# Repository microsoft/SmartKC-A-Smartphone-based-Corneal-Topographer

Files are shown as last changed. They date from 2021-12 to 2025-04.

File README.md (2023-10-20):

# SmartKC: Analysis Pipeline

This directory contains the code for the image processing pipeline for *SmartKC*. The input to the system is a *mire* image and the output are the corneal topography heatmaps (*axial* and *tangential*), along with the quantitative metrics: *sim-k, diff, mean-k, aCLMI, PPK, KISA*.

The aim of this README is to describe in detail the setup and image processing pipeline for ease of understanding and usage by a beginner user. The readme describes in detail the analysis pipeline, example code snippets, details on the functions and parameters.

The figure below illustrates the (a) SmartKC system setup, (b) LED light arrangement, (c) 3D-printed conical placido clip-on attachment, (d) image capture of a subject’s eye, and (e) captured image of the cornea with
placido disc reflection (called mires).

<p align='center'>
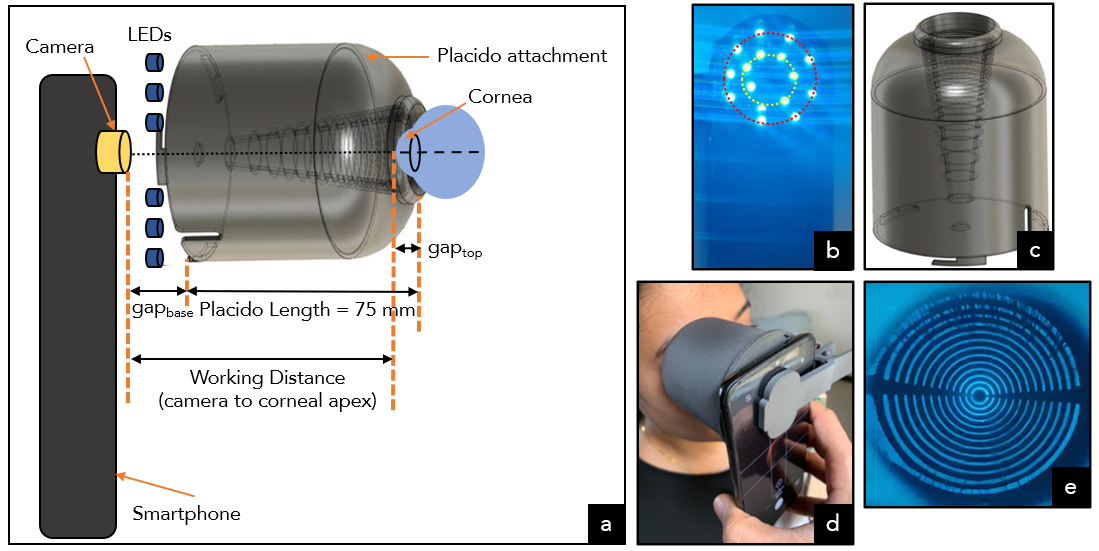
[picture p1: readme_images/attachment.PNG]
      
</p>

## Dependencies

```
* Python3.8.XX
* numpy==1.18.1
* opencv-contrib-python==4.4.0.46
* scikit-image==0.18.1
* scikit-learn
* scipy
* zernike==0.0.15
* pandas==1.1.1
* matplotlib==3.2.2
* Flask==1.1.2
* seaborn==0.11.0
* tqdm==4.56.0
* Pytorch (torch, torchvision and other dependencies for Pytorch)
```

These are all easily installable via, e.g., `pip install numpy`. Any reasonably recent version of these packages should work. It is recommended to use a python `virtual` environment to setup the dependencies and the code.

### External Libraries

* [Zernike](https://github.com/jacopoantonello/zernike)
* [Fingerprint-Enhancement-Python](https://github.com/Utkarsh-Deshmukh/Fingerprint-Enhancement-Python)

**Note**: The zernike polynomial smoothening function has been modified from the version above. Please use the module at location: `/SmartKC/data/zernike` (I yet am to make a pull request to the original repository).

## Image Processing Pipeline Overview

<p align='center'>
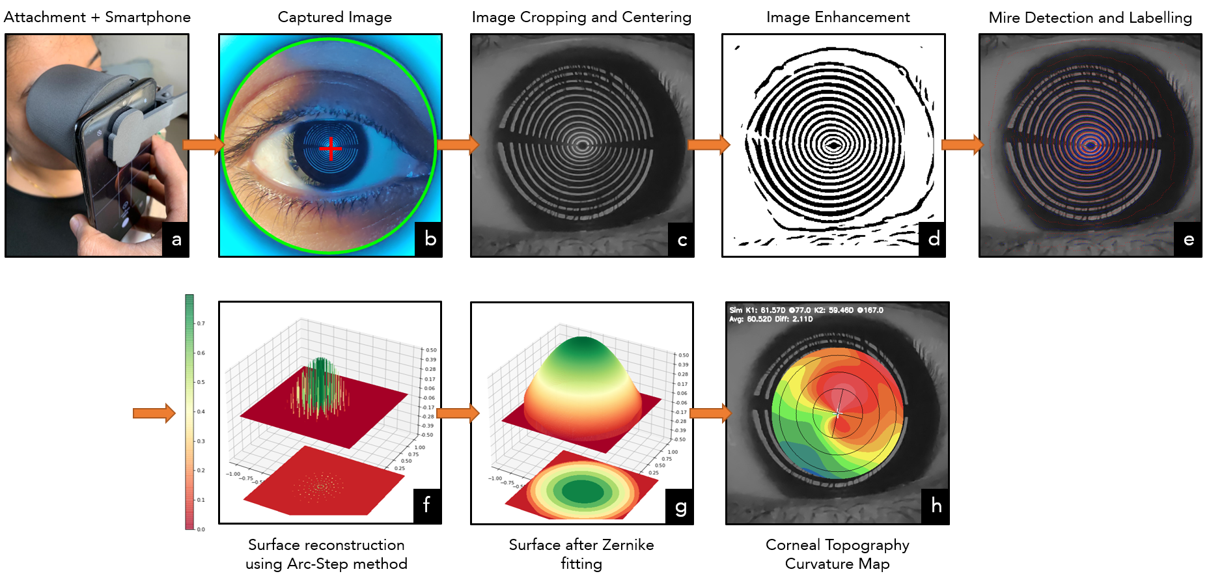
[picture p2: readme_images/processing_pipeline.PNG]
      
</p>

The image analysis pipeline takes as input the image collected via our setup (3D attachment and smartphone), and outputs the corneal topography heatmaps along with quantitative values. The analysis pipeline first performs **pre-processing** (*image cropping, mire segmentation, and center detection*) on the input image. The next step is to get the **mire-placido mapping**, this is followed by estimation of **placido ring location and working distance**. The final corneal topography is estimated by running the **Arc-Step method** followed by zernike polynomial based smoothening.

## Example Code Snippet:

```python
from main import *

# assuming args has camera-parameters, base_dir, start/end angle, jump, model-file, working_distance, number of mires, upsample flag

# getting parameters for corneal_top_obj
f_inv_20_5 = np.poly1d([3583.52156815, -17.31674123]) # 5 mm gap2, mire_21, id_20
sensor_dims = (
    float(args.camera_params.split()[0]),
    float(args.camera_params.split()[1]),
)  # "4.27, 5.68, 4.25"
f_len = float(args.camera_params.split()[2]) # focal length of the camera

# create the corneal_top_gen class object
corneal_top_obj = corneal_top_gen(
    args.model_file, args.working_distance, sensor_dims, 
    f_len, args.start_angle, args.end_angle, args.jump, 
    args.upsample, args.n_mires, f_inv_20_5,
    )

# get details for current test image
base_dir = args.base_dir  # base directory
skip_angles = [[-1, -1], [-1, -1]]
center = (-1, -1)
image_name = "./data/test_image.jpg"

# call function to run pipeline and generate_topography_maps
# expects image to be in .jpg format
error = corneal_top_obj.generate_topography_maps(
    base_dir,
    image_name,
    center=center,
    downsample=True,
    blur=True,
    err1=[args.gap1],
    err2=[args.gap2],
    )
```

**Note**: To understand the different parameters, please go through the detailed documentation for each function and the input parameters below.

## Running Script

`python main.py --n_mires 22 --working_distance 75.0 --camera_params "4.8 6.4 4.755" --model_file ./data/ring_distribution.txt --base_dir data/sample_images/ --center_selection auto --mire_seg_method dl --mire_loc_method graph_cluster --verbose`

Please place your csv files containing meta data generated by the smart kc app in the `base_dir` if you want the pipeline to automatically pick up the center values as marked in the smartkc app

There are 2 arguments which control how the segmentation and mire localization is done. 

(1) `--mire_seg_method` determines how the mires are segmented. Currently, we support 2 methods for segmentation, `image_proc` which does segmentation via traditional image processing, and `dl` which does image segmentation using a U-Net based segmentor model.

(2) `--mire_loc_method` determines how mires are localized. Currently, we support 2 methods - `radial_scan` which determines mire locations via the radial-scanning algorithm mentioned in the paper, and `graph_cluster` which applies graph-based connected-component search to locate mires by utilizing spatial information. More details coming.

We also support a `--verbose` flag to turn on logging, if required.

## Sample outputs

<p align='center'>
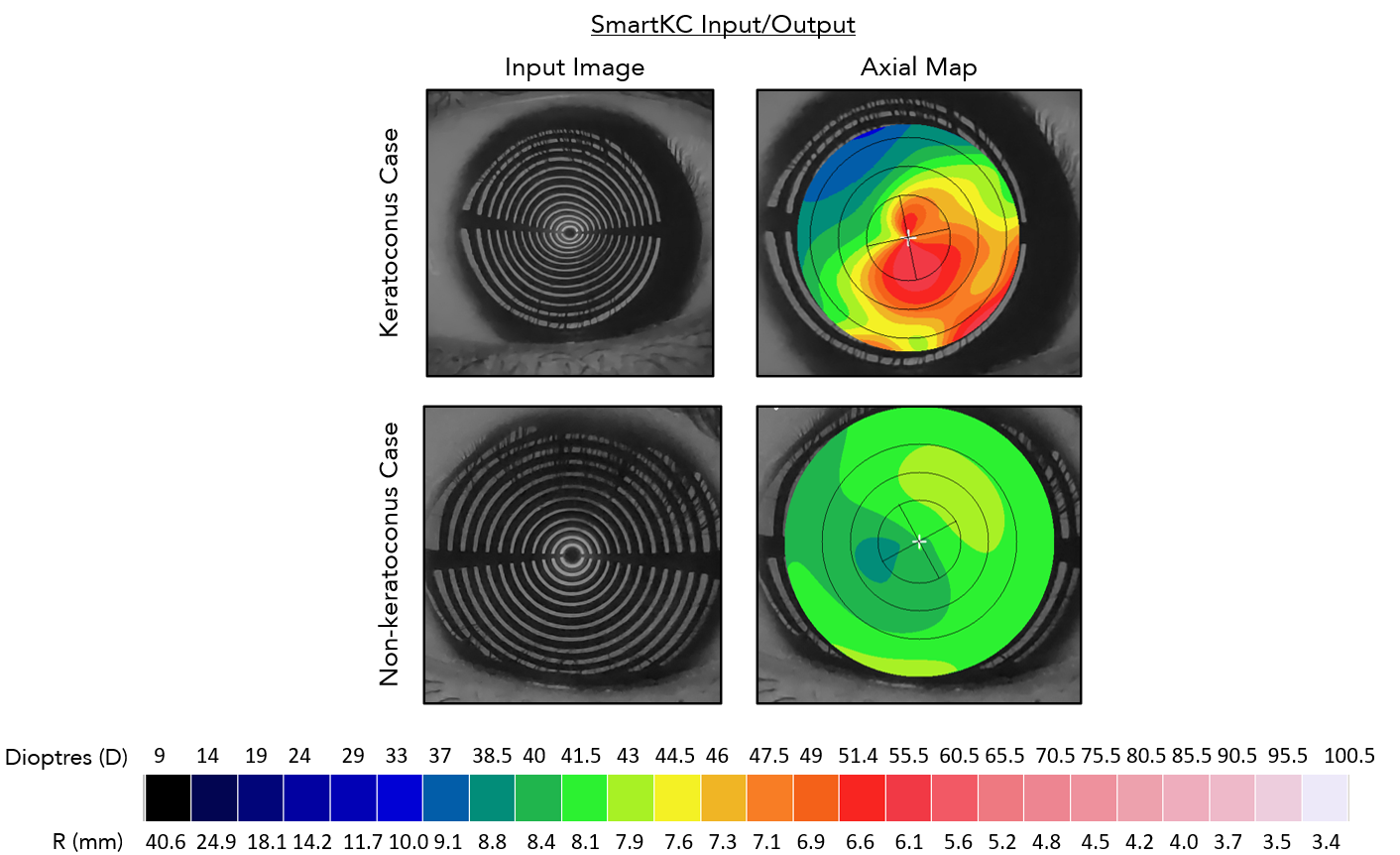
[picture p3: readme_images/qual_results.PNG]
      
</p>

## About the code:

* `main.py` : This is the main runner file which has the `corneal_topography_generator` class.

* `preprocess.py` : Preprocessing module, which takes as input the mire image, performs center detection and mire segmentation.
* `mire_detection.py` : Detects the pixel locations of the mires via the *radial scanning* algorithm along with *anti-aliasing* and *outlier* removal.
* `mire_detection_dl.py` and `mire_detection_graph.py` : Detect mires using `dl-radial-scanning` and `graph_cluster` (for both `dl` and `image_proc`) mire localization methods, respectively 
* `camera_size.py`: Gets the actual 3D Placido locations using the placido model dimensions and camera parameters.
* `segment_mires.py` : Segments mires based on the method (`image_proc` or `dl`) used.
* `arc_step_method.py`: Runs the *Arc Step* method.
* `get_maps.py` : Generates the corneal topography maps from the zernike smoothened surface.
* `metrics.py` : Computes the quantitative metrics like *sim-K, aCLMI, PPK, KISA, tilt-factor*.
* `utils.py`: Contains supporting utility functions for line-plotting, drawing, etc.

### Additional Modules

* `enhance_img` : contains the src files for the mire enhancement and segmentation algorithm.
* `iris_detection` : UNet based model for iris segmentation.
* `misc_scripts` : Contains scripts for evaluation and data processing.

## Documentation

**class corneal_top_gen** : main runner class for processing the input image.

```python
corneal_top_gen(
        model_file, 
        working_distance, 
        sensor_dims,
        f_len, 
        start_angle, 
        end_angle, 
        jump, 
        upsample, 
        n_mires, 
        f_gap1, 
        zernike_degree=[8],
        test_name=None
        )
```
The class object, parameters:

* `model_file`: file which consists of the placido head dimensions
* `working_distance`: distance between camera pupil and cornea apex
* `sensor_dims` : width x height of camera sensor
* `f_len` : focal length of camera
* `f_gap1`: function which maps 1/mire-21-radius to gap1
* `start_angle`: start meridian
* `end_angle` : end meridian
* `jump`: diff between the consec angles when processing mires
* `upsample` : if the image has to be upsampled or not
* `n_mires` : number of mires to process
* `zernike_degree` : degree of the zernike polynomial used for fitting
* `test_name` : usually the date the test was conducted (all samples for that day are stored in this directory)

**generate_topography_maps**: main runner function to generate topography maps from input image.

```python
generate_topography_maps(
        base_dir, 
        image_name, 
        crop_dims=(1200,1200), 
        iso_dims=500, 
        center=(-1, -1), 
        downsample=False, 
        blur=True, 
        upsample=None,
        err1=[0], 
        err2=[0], 
        skip_angles=[[-1, -1], [-1, -1]],
        center_selection="manual",
    )
```

* `base_dir` : directory containing all the input images.
* `image_name` : test image name.
* `crop_dims` : dimensions for initial crop of the central region (this is before center detection).
* `iso_dims` : dimensions of only the central region, which is the tightest bounding box for the iris.
* `center` : center point of the mires. If this is (-1, -1) then can either select the center automatically or manually.
* `downsample` : true / false to downsample the image or not (speeds up processing of mire segmentation).
* `blur` : should blur filter be applied before mire segmentation.
* `upsample`: if the image has to be upsampled or not.
* `err1` : the value of gapTop in mm, can be positive or negative real number.
* `err2` : the value of gapBase in mm, is always a positive real number.
* `skip_angles` : the meridians to skip during processing (usually the blank spaces due to supports are ignored).
* `center_selection` : flag can be "auto" for automatic center detection or "manual" for manually selecting the center.

**run_arc_step_gen_maps** : function which runs the Arc-step method on the detected mire pixel locations, 3D placido ring locations, slope, working distance and camera parameters.

```
run_arc_step_gen_maps(
    image_seg,
    image_name,
    center, 
    coords, 
    h, w, 
    err1=0, 
    err2=0
    )
```

* `image_seg` : segmented mire image.
* `image_name` : name of input image.
* `center` : center of the mires.
* `coords` : pixel locations of the detected mires.
* `h, w` : height and width of the original un-cropped image in pixels.
* `err1` : gapTop in mm.
* `err2` : gapBase in mm

**zernike_smoothening** : function to perform zernike smoothening.

```python
zernike_smoothening(
    image_name, 
    plot_x, 
    plot_y, 
    plot_z, 
    xy_norm, 
    xv, 
    yv, 
    max_r, 
    relative_points
    )
```

* `image_name` : name of the input image
* `plot_x` : list or numpy array of the x coordinates of the corneal points fitted by Arc-step method.
* `plot_y` : list or numpy array of the y coordinates of the corneal points fitted by Arc-step method.
* `plot_z` : list or numpy array of the z coordinates (or elevation value) of the corneal points fitted by Arc-step method.
* `xy_norm` : factor to normalize x and y coordinates to lie within a unit circle.
* `xv, yv` : mesh grid for the extent of x and y.
* `max_r` : maximum radius value in pixels
* `relative_points`: relative location of each mire pixel location w.r.t to the center.

**Note** : The image processing pipeline for now only supports images with "jpg" format, and resolution of `3000x4000` pixels. For zoomed-in images please re-scale and pad accordingly before running the pipeline.

## SmartKC Mobile App

* Please find the source for the SmartKC Android Mobile App that was used as part of the study here: `SmartKC-A-Smartphone-based-Corneal-Topographer/mobile_app/smartkc_mobile_app_src`.
* The app can be set up with Azure functions to automatically upload the images on the cloud by following these [instructions.](https://github.com/microsoft/SmartKC-A-Smartphone-based-Corneal-Topographer/blob/main/azure_function/file_uploader/Install.md)

## SmartKC Hardware
* The STL files for the placido head, diffuser, and placido base are located at: `hardware/placido_head.stl`, `hardware/diffuser.stl`, and `hardware/placido_base.stl` respectively, along with the instructions to 3D print them.
* Details related to the development board (and its source code), LED ring, smartphone specifications, assembly instructions, etc. are present in the `hardware` folder.

# Disclaimer
**The software and hardware described in this repository is provided for research and development use only. The software and hardware are not intended for use in clinical decision-making or for any other clinical use, and their performance for clinical use has not been established. You bear sole responsibility for any use of this software and hardware, including incorporation into any product intended for clinical use.**

# Contributing

This project welcomes contributions and suggestions.  Most contributions require you to agree to a
Contributor License Agreement (CLA) declaring that you have the right to, and actually do, grant us
the rights to use your contribution. For details, visit https://cla.opensource.microsoft.com.

When you submit a pull request, a CLA bot will automatically determine whether you need to provide
a CLA and decorate the PR appropriately (e.g., status check, comment). Simply follow the instructions
provided by the bot. You will only need to do this once across all repos using our CLA.

This project has adopted the [Microsoft Open Source Code of Conduct](https://opensource.microsoft.com/codeofconduct/).
For more information see the [Code of Conduct FAQ](https://opensource.microsoft.com/codeofconduct/faq/) or
contact [opencode@microsoft.com](mailto:opencode@microsoft.com) with any additional questions or comments.

# Legal Notices

Microsoft and any contributors grant you a license to the Microsoft documentation and other content
in this repository under the [Creative Commons Attribution 4.0 International Public License](https://creativecommons.org/licenses/by/4.0/legalcode),
see the [LICENSE](LICENSE) file, and grant you a license to any code in the repository under the [MIT License](https://opensource.org/licenses/MIT), see the
[LICENSE-CODE](LICENSE-CODE) file.

Microsoft, Windows, Microsoft Azure and/or other Microsoft products and services referenced in the documentation
may be either trademarks or registered trademarks of Microsoft in the United States and/or other countries.
The licenses for this project do not grant you rights to use any Microsoft names, logos, or trademarks.
Microsoft's general trademark guidelines can be found at http://go.microsoft.com/fwlink/?LinkID=254653.

Privacy information can be found at https://privacy.microsoft.com/en-us/

Microsoft and any contributors reserve all other rights, whether under their respective copyrights, patents,
or trademarks, whether by implication, estoppel or otherwise.

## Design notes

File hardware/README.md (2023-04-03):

# Phone Attachment

## Requirement:
1. **Placido head**: 3D-print `placido_head.stl` (to modify the design, use `placido_head.step`) by following the 3D-print related instructions [below](#placido-head)
1. **Placido base**: 3D-print `placido_base.stl` (to modify the design, use `placido_base.step`) by following the 3D-print related instructions [below](#placido-base)
1. **Diffuser**: 3D-print `diffuser.stl` (to modify the design, use `diffuser.step`) by following the 3D-print related instructions [below](#diffuser)
1. **Circular LED**: Use WS2812/WS2812B 12-bit RGB LED Ring (available for Rs 250 or 3$ on DigiKey, [Robocraze](https://robocraze.com/products/ws2812-12-bit-rgb-led-round), [ThinkRobotics](https://thinkrobotics.in/products/ws2812-5050-rgb-led-ring), etc.)
1. **Development board**: Use ATtiny85 (Digispark) USB Development Board (available for Rs 325 or 4$ on DigiKey, [Robocraze](https://robocraze.com/products/attiny85-usb-development-board), [Robu](https://robu.in/product/attiny85-usb-development-board/), etc.)
1. **Source code for Development board**: Use `attiny85_led_setup_code.ino` code and upload it in the ATtiny85 development board by following the instructions [below](#attiny85-development-board-related-instructions)
1. **OTG cable**: To connect ATtiny85 Development Board with the smartphone charging input, use a USB-A Female to USB-B/C Male cable (available for Rs 200 or 2.5$ on [Amazon](https://www.amazon.in/gp/product/B012V56C8K))
1. **Double-sided tape**: Use 3M Scotch Double Sided Foam Tape (available for Rs 100 or 1.2$ on [Amazon](https://www.amazon.in/gp/product/B00N1U9AJS/))
1. **Smartphone Case**: Specific to your smartphone
1. **Smartphone**: Please check the smartphone specification related requirement [below](#smartphone-specifications)

Note: Kindly follow the guidelines mentioned in the `guidelines_for_data_collector.pdf` document to collect high-quality data from the SmartKC device.

## Ring Distribution
File `./ring_distribution.txt` contains the radius of each ring and its height from the base.

## 3D-print Instructions:

### Placido head:
MJF (MultiJet Fusion) print with PA-12 material in Stone Grey color (Matt finish). We used the default settings.

### Placido base:
MJF (MultiJet Fusion) print with PA-12 material in Stone Grey color (Matt finish). We used the default settings.

### Diffuser:
Print using PLA material (white filament): [1.75mm PLA_3D Filament White 1KG](https://robu.in/product/esun-pla-1-75mm-3d-printing-filament-1kg-white/). White-colored filament is required to achieve translucency. Note: Convert the `.stl` file to `.gx` file before printing.

We used the FlashForge Finder 3D printer with [FlashPrint](https://flashforge-usa.com/pages/download) software (version 4.20, 64 Bits), with the following settings: 
* First Layer Height: 0.25 mm, 
* Layer Height: 0.20 mm, 
* Infill: 30%, 
* Fill pattern: Hexagonal, 
* Temperature: 225C,
* Resolution: High.

## ATtiny85 Development Board-related Instructions:
1. Download Arduino IDE (.exe file) from [here](https://www.arduino.cc/en/software) on Windows 7 or newer, and install it.
1. To program Digispark ATtiny85 development board, follow the instructions from [here](http://digistump.com/wiki/digispark/tutorials/connecting)
    1. Download device drivers from [here](https://github.com/digistump/DigistumpArduino/releases/download/1.6.7/Digistump.Drivers.zip). Unzip and run `DPInst64.exe`
    1. Open the installed Arduino IDE. Go to the `File`→`Preferences` menu. In the box labeled `Additional Boards Manager URLs` enter: http://digistump.com/package_digistump_index.json.
    1. Go to the `Tools`→`Board`→`Boards Manager` menu. From the `Type` drop-down, select `Contributed`. Select the `Digistump AVR Boards` package and click the `Install` button. After the installation completes, close the `Boards Manager` window.
    1. Go to the `Tools`→`Boards`→`Digistump AVR Boards` and select `Digispark (Default - 16.5mhz)` board.
    1. DO NOT CONNECT THE USB BOARD TO YOUR COMPUTER.
    1. Copy the [test code](http://digistump.com/wiki/digispark/tutorials/connecting) into Arduino IDE. Click the `Upload` button. When asked connect the USB board, and see it working.
1. Copy the `attiny85_led_setup_code.ino` source code into Arduino IDE. Click the `Upload` button. 

## Smartphone Specifications:
* Android smartphone with 12 MP (or more) back camera with a minimum focusing distance of 75mm (or less).
* Devices we have tested SmartKC to work well on: OnePlus 7T, OnePlus 6T, Samsung Galaxy A52s 5G, Xiaomi Pocophone F1.
* Devices we have tested SmartKC to not work on: OnePlus 9 5G, Redmi 9 Power, Pixel 4a. Reason: minimum focusing distance too high.

## Assembly Instructions (putting it all together):
1. Upload the `attiny85_led_setup_code.ino` code to the `Development board`.
1. Connect the `Circular LED` to the `Development board` by soldering ATtiny85 GND to WS2812 GND, ATtiny85 5V to WS2812 5V, and ATtiny85 P1 to WS2812 D1.
1. Use `Double-sided tape` to attach the `Circular LED` on the `Placido base` (aligning it with the center).
1. Use `Double-sided tape` to attach the `Development board` on the `Placido base` (inside the igloo shaped enclosure)
1. Use `Double-sided tape` to attach the `Placido base` over the `Smartphone Case`.
   * Important: Make sure to align the hole on the `Placido base` with the smartphone's main back camera.
   * Also, orient the `Placido base` such that the `Development board` enclosure aligns vertically with the phone.
1. Connect the `Development board` to the smartphone using the `OTG cable`.
1. Place the `Diffuser` inside the `Placido head`.
1. Attach the `Placido head` (with `Diffuser` inside it) to the `Placido base` by placing the three pegs and rotating it.

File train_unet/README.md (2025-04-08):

# Training the U-Net mire segmentation model

Here, we outline the steps to generate the data and train the U-Net model for mire segmentation.

## Step-1: Generate the mire masks using `mire_seg_method="img_proc"` in the main pipeline.
First, we created a data directory within the `train_unet` dir.
We put all collected images in the `images` directory within the `data` dir and run the SmartKC pipeline on the images by running:

`python main.py --n_mires 22 --working_distance 75.0 --camera_params "4.8 6.4 4.755" (or your camera params) --model_file ./data/ring_distribution.txt --base_dir ./data/images/ --center_selection auto --mire_seg_method img_proc --mire_loc_method graph_cluster --verbose`

Then, we copied the `<image_name>_seg.png` files into the `image_masks_clean` dir within the `data` dir. We removed failure cases of the image processing from this folder, and only kept clean masks.

## Step-2: Generate instance masks for mire segmentation from the generated data.
Next, we use the binary masks generated using image processing to generate the segmented mire numbers. For this, we run,

`python get_connected_components.py`

This generated instance mire masks from binary masks (see below).

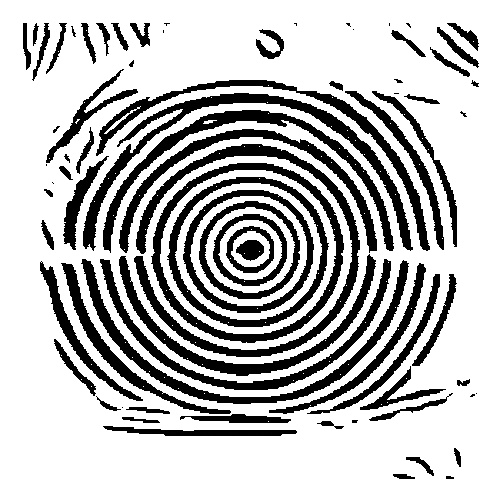
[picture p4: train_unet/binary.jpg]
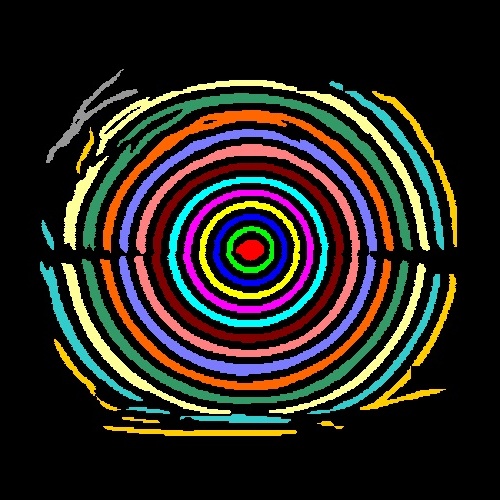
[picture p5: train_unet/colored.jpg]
 

## Step-3: Generate train/test data for training the U-Net model.
We randomly split the images in `images` dir into train/test set. (80/20 split). We generate the `train.txt` and `test.txt` file, where each line in the file is an image name.

## Step-4: Train the U-Net model
Next, we trained the U-Net model by running the following script - 

`python train.py --lr 1e-3 --num_worker 4 --batch_size 12 --epochs 1000 --start_epochs 0 --image_size 512 --train_data ../data/image_masks_clean --val_data ../data/image_masks_clean --train_txt ../data/train.txt --val_txt ../data/test.txt --train_label ../data/components --val_label ../data/components --model_path ./model_out`

We use the last `best_epoch_x_iter_y.pkl` model as the segmentation model.

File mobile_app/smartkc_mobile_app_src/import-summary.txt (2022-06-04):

ECLIPSE ANDROID PROJECT IMPORT SUMMARY
======================================

Ignored Files:
--------------
The following files were *not* copied into the new Gradle project; you
should evaluate whether these are still needed in your project and if
so manually move them:

* javadoc\
* javadoc\allclasses-frame.html
* javadoc\allclasses-noframe.html
* javadoc\constant-values.html
* javadoc\help-doc.html
* javadoc\index-all.html
* javadoc\index.html
* javadoc\org\
* javadoc\org\opencv\
* javadoc\org\opencv\android\
* javadoc\org\opencv\android\BaseLoaderCallback.html
* javadoc\org\opencv\android\CameraBridgeViewBase.CvCameraViewFrame.html
* javadoc\org\opencv\android\CameraBridgeViewBase.CvCameraViewListener.html
* javadoc\org\opencv\android\CameraBridgeViewBase.CvCameraViewListener2.html
* javadoc\org\opencv\android\CameraBridgeViewBase.ListItemAccessor.html
* javadoc\org\opencv\android\CameraBridgeViewBase.html
* javadoc\org\opencv\android\FpsMeter.html
* javadoc\org\opencv\android\InstallCallbackInterface.html
* javadoc\org\opencv\android\JavaCameraView.JavaCameraSizeAccessor.html
* javadoc\org\opencv\android\JavaCameraView.html
* javadoc\org\opencv\android\LoaderCallbackInterface.html
* javadoc\org\opencv\android\NativeCameraView.OpenCvSizeAccessor.html
* javadoc\org\opencv\android\NativeCameraView.html
* javadoc\org\opencv\android\OpenCVLoader.html
* javadoc\org\opencv\android\Utils.html
* javadoc\org\opencv\android\package-frame.html
* javadoc\org\opencv\android\package-summary.html
* javadoc\org\opencv\android\package-tree.html
* javadoc\org\opencv\calib3d\
* javadoc\org\opencv\calib3d\Calib3d.html
* javadoc\org\opencv\calib3d\StereoBM.html
* javadoc\org\opencv\calib3d\StereoSGBM.html
* javadoc\org\opencv\calib3d\package-frame.html
* javadoc\org\opencv\calib3d\package-summary.html
* javadoc\org\opencv\calib3d\package-tree.html
* javadoc\org\opencv\core\
* javadoc\org\opencv\core\Algorithm.html
* javadoc\org\opencv\core\Core.MinMaxLocResult.html
* javadoc\org\opencv\core\Core.html
* javadoc\org\opencv\core\CvException.html
* javadoc\org\opencv\core\CvType.html
* javadoc\org\opencv\core\Mat.html
* javadoc\org\opencv\core\MatOfByte.html
* javadoc\org\opencv\core\MatOfDMatch.html
* javadoc\org\opencv\core\MatOfDouble.html
* javadoc\org\opencv\core\MatOfFloat.html
* javadoc\org\opencv\core\MatOfFloat4.html
* javadoc\org\opencv\core\MatOfFloat6.html
* javadoc\org\opencv\core\MatOfInt.html
* javadoc\org\opencv\core\MatOfInt4.html
* javadoc\org\opencv\core\MatOfKeyPoint.html
* javadoc\org\opencv\core\MatOfPoint.html
* javadoc\org\opencv\core\MatOfPoint2f.html
* javadoc\org\opencv\core\MatOfPoint3.html
* javadoc\org\opencv\core\MatOfPoint3f.html
* javadoc\org\opencv\core\MatOfRect.html
* javadoc\org\opencv\core\Point.html
* javadoc\org\opencv\core\Point3.html
* javadoc\org\opencv\core\Range.html
* javadoc\org\opencv\core\Rect.html
* javadoc\org\opencv\core\RotatedRect.html
* javadoc\org\opencv\core\Scalar.html
* javadoc\org\opencv\core\Size.html
* javadoc\org\opencv\core\TermCriteria.html
* javadoc\org\opencv\core\package-frame.html
* javadoc\org\opencv\core\package-summary.html
* javadoc\org\opencv\core\package-tree.html
* javadoc\org\opencv\features2d\
* javadoc\org\opencv\features2d\DMatch.html
* javadoc\org\opencv\features2d\DescriptorExtractor.html
* javadoc\org\opencv\features2d\DescriptorMatcher.html
* javadoc\org\opencv\features2d\FeatureDetector.html
* javadoc\org\opencv\features2d\Features2d.html
* javadoc\org\opencv\features2d\GenericDescriptorMatcher.html
* javadoc\org\opencv\features2d\KeyPoint.html
* javadoc\org\opencv\features2d\package-frame.html
* javadoc\org\opencv\features2d\package-summary.html
* javadoc\org\opencv\features2d\package-tree.html
* javadoc\org\opencv\highgui\
* javadoc\org\opencv\highgui\Highgui.html
* javadoc\org\opencv\highgui\VideoCapture.html
* javadoc\org\opencv\highgui\package-frame.html
* javadoc\org\opencv\highgui\package-summary.html
* javadoc\org\opencv\highgui\package-tree.html
* javadoc\org\opencv\imgproc\
* javadoc\org\opencv\imgproc\CLAHE.html
* javadoc\org\opencv\imgproc\Imgproc.html
* javadoc\org\opencv\imgproc\Moments.html
* javadoc\org\opencv\imgproc\Subdiv2D.html
* javadoc\org\opencv\imgproc\package-frame.html
* javadoc\org\opencv\imgproc\package-summary.html
* javadoc\org\opencv\imgproc\package-tree.html
* javadoc\org\opencv\ml\
* javadoc\org\opencv\ml\CvANN_MLP.html
* javadoc\org\opencv\ml\CvANN_MLP_TrainParams.html
* javadoc\org\opencv\ml\CvBoost.html
* javadoc\org\opencv\ml\CvBoostParams.html
* javadoc\org\opencv\ml\CvDTree.html
* javadoc\org\opencv\ml\CvDTreeParams.html
* javadoc\org\opencv\ml\CvERTrees.html
* javadoc\org\opencv\ml\CvGBTrees.html
* javadoc\org\opencv\ml\CvGBTreesParams.html
* javadoc\org\opencv\ml\CvKNearest.html
* javadoc\org\opencv\ml\CvNormalBayesClassifier.html
* javadoc\org\opencv\ml\CvParamGrid.html
* javadoc\org\opencv\ml\CvRTParams.html
* javadoc\org\opencv\ml\CvRTrees.html
* javadoc\org\opencv\ml\CvSVM.html
* javadoc\org\opencv\ml\CvSVMParams.html
* javadoc\org\opencv\ml\CvStatModel.html
* javadoc\org\opencv\ml\EM.html
* javadoc\org\opencv\ml\Ml.html
* javadoc\org\opencv\ml\package-frame.html
* javadoc\org\opencv\ml\package-summary.html
* javadoc\org\opencv\ml\package-tree.html
* javadoc\org\opencv\objdetect\
* javadoc\org\opencv\objdetect\CascadeClassifier.html
* javadoc\org\opencv\objdetect\HOGDescriptor.html
* javadoc\org\opencv\objdetect\Objdetect.html
* javadoc\org\opencv\objdetect\package-frame.html
* javadoc\org\opencv\objdetect\package-summary.html
* javadoc\org\opencv\objdetect\package-tree.html
* javadoc\org\opencv\photo\
* javadoc\org\opencv\photo\Photo.html
* javadoc\org\opencv\photo\package-frame.html
* javadoc\org\opencv\photo\package-summary.html
* javadoc\org\opencv\photo\package-tree.html
* javadoc\org\opencv\utils\
* javadoc\org\opencv\utils\Converters.html
* javadoc\org\opencv\utils\package-frame.html
* javadoc\org\opencv\utils\package-summary.html
* javadoc\org\opencv\utils\package-tree.html
* javadoc\org\opencv\video\
* javadoc\org\opencv\video\BackgroundSubtractor.html
* javadoc\org\opencv\video\BackgroundSubtractorMOG.html
* javadoc\org\opencv\video\BackgroundSubtractorMOG2.html
* javadoc\org\opencv\video\KalmanFilter.html
* javadoc\org\opencv\video\Video.html
* javadoc\org\opencv\video\package-frame.html
* javadoc\org\opencv\video\package-summary.html
* javadoc\org\opencv\video\package-tree.html
* javadoc\overview-frame.html
* javadoc\overview-summary.html
* javadoc\overview-tree.html
* javadoc\package-list
* javadoc\resources\
* javadoc\resources\inherit.gif
* javadoc\serialized-form.html
* javadoc\stylesheet.css

Moved Files:
------------
Android Gradle projects use a different directory structure than ADT
Eclipse projects. Here's how the projects were restructured:

* AndroidManifest.xml => openCVLibrary2411\src\main\AndroidManifest.xml
* lint.xml => openCVLibrary2411\lint.xml
* res\ => openCVLibrary2411\src\main\res\
* src\ => openCVLibrary2411\src\main\java\
* src\org\opencv\engine\OpenCVEngineInterface.aidl => openCVLibrary2411\src\main\aidl\org\opencv\engine\OpenCVEngineInterface.aidl

Next Steps:
-----------
You can now build the project. The Gradle project needs network
connectivity to download dependencies.

Bugs:
-----
If for some reason your project does not build, and you determine that
it is due to a bug or limitation of the Eclipse to Gradle importer,
please file a bug at http://b.android.com with category
Component-Tools.

(This import summary is for your information only, and can be deleted
after import once you are satisfied with the results.)

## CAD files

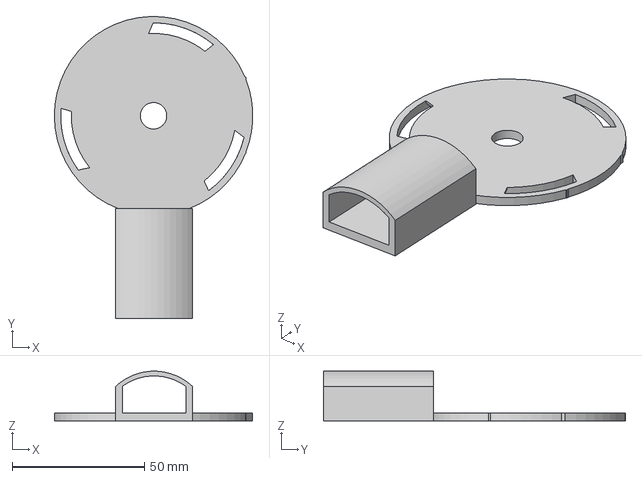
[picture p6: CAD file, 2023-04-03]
hardware/placido_base.step
74.9 x 114.0 x 18.7 mm

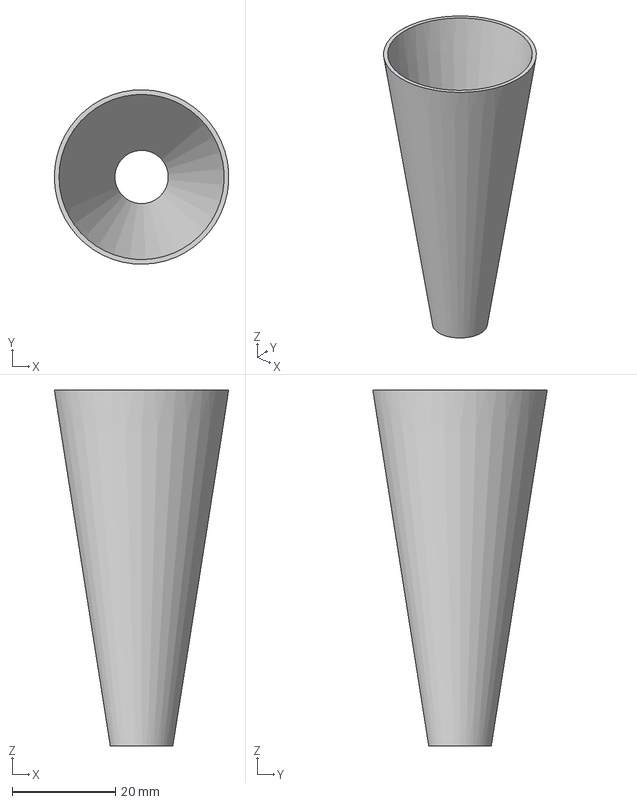
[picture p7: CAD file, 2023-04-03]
hardware/diffuser.step
33.8 x 33.8 x 69.0 mm

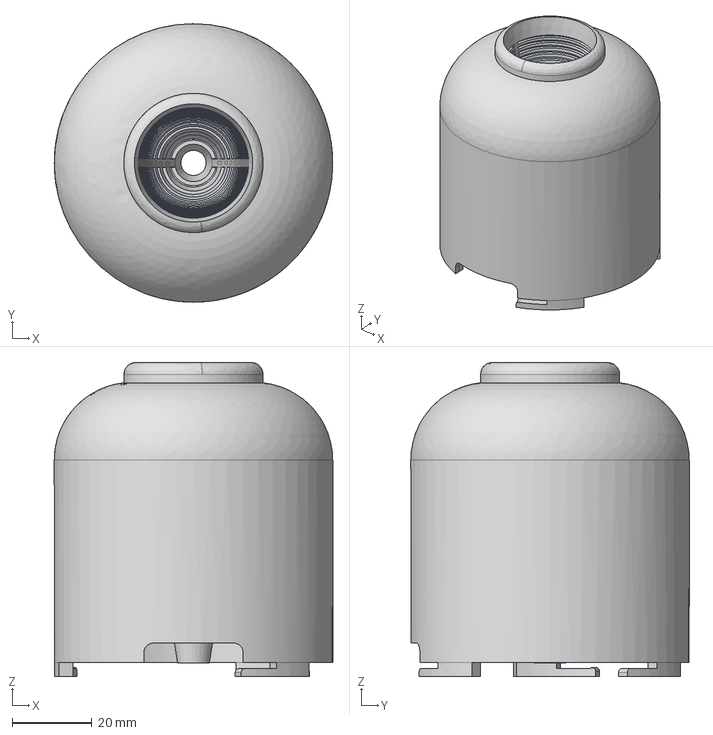
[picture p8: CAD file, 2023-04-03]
hardware/placido_head.step
70.0 x 70.0 x 78.9 mm

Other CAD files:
hardware/diffuser.stl
hardware/placido_base.stl
hardware/placido_head.stl

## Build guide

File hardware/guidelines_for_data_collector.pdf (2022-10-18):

## Guidelines for Keratoconus Data Collection

## Instructions to the Patient

1. Ask the patient to close one-eye with their hand.
2. Ask the patient to blink a few times and keep the other eye wide open.
3. Ask the patient to look at the camera (center of the rings).

## Instructions to the Operator

During data collection, please ensure:
1. Correctly enter the patient id, age and gender.
2. Ensure that the LED lights are ON (blue color will appear on the screen).
3. Place the attachment around the patient’s eye orbit.
4. Both the top and bottom part of the attachment should touch the face.
5. The ring reflections should be centered.
6. The camera is in focus. Please tap to focus, if not.
7. Reflection image (mires) should cover limbus to limbus.
a. NO minified images.
8. The two side supports should be horizontal.

## To select an image (out of the three clicked images):

1. The image is in focus, with no blur.
2. The two side supports are horizontal.
3. The ring reflections are centered.
4. Good limbus to limbus coverage.

Note:
- At the end of each day, upload the reports (mire image, axial image, and/or tangential image) from Keratron and/or Occulyzer device.
- Note: Internet connection is required for SmartKC App to upload data.

For each patient, perform the following steps:
1. Optikon Keratron or Occulyzer Test.
2. Collect data from the phone app with placido attachment.

## Good and Bad Image Examples

If the above guidelines are not followed properly, it may result in a bad image capture that can lead to incorrectly generated topography maps and a misleading diagnosis. Hence, it is of utmost importance to follow guidelines properly at all times. Below are examples of good and bad image scenarios, that can act as a reference when training an operator to use the SmartKC device to capture perfect images:

Good Image Examples

1.Mires sharp and in-focus, limbus-to-limbus coverage, support horizontal, no offset

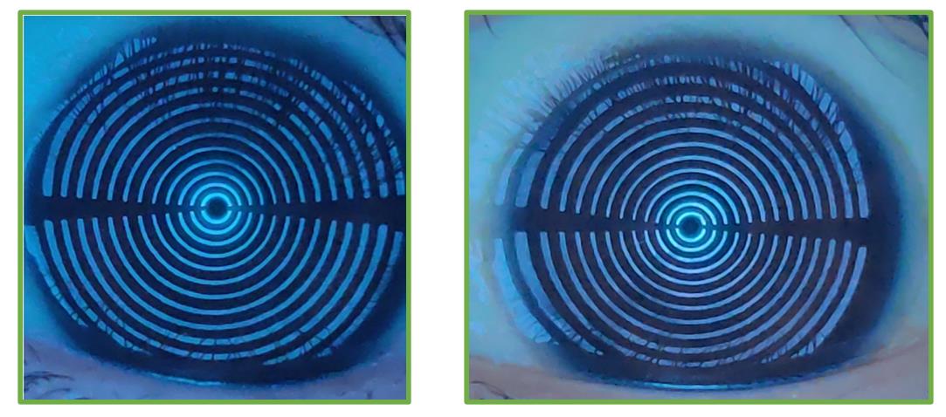
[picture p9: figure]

Bad Image Examples

1. Bad limbus-to-limbus coverage (minified image), outside reflections visible (placido head not touching area around eye orbital well)

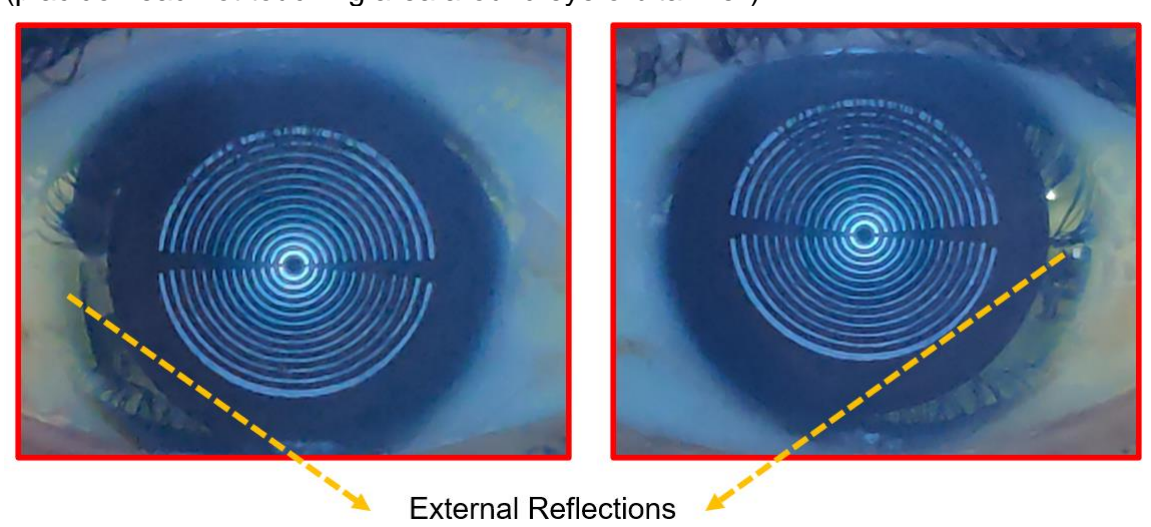
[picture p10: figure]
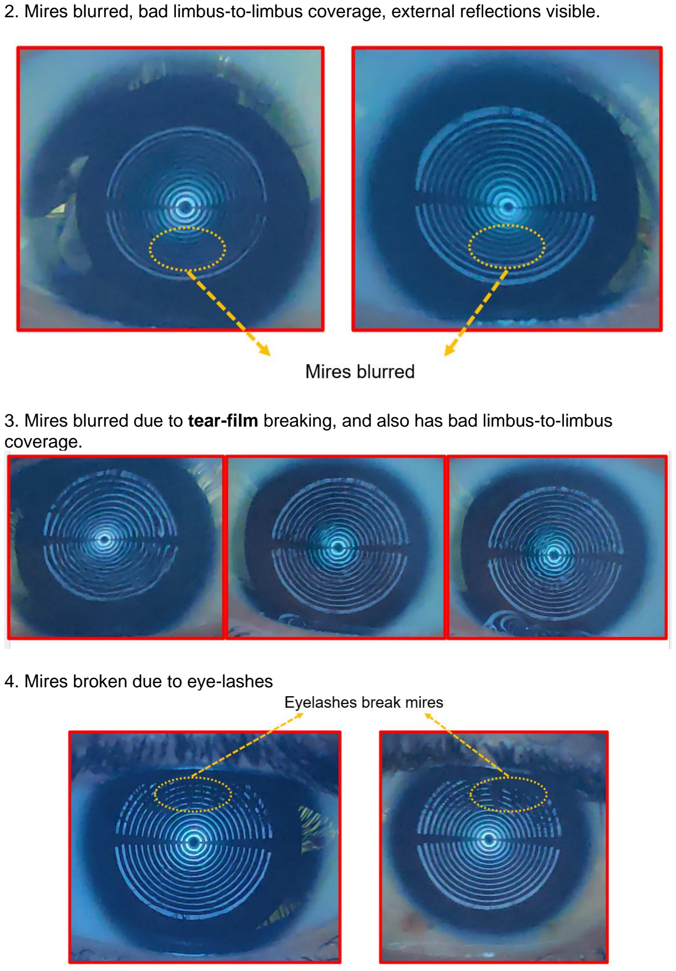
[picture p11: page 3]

2. Mires blurred, bad limbus-to-limbus coverage, external reflections visible.
3. Mires blurred due to tear-film breaking, and also has bad limbus-to-limbus coverage.
4. Mires broken due to eye-lashes

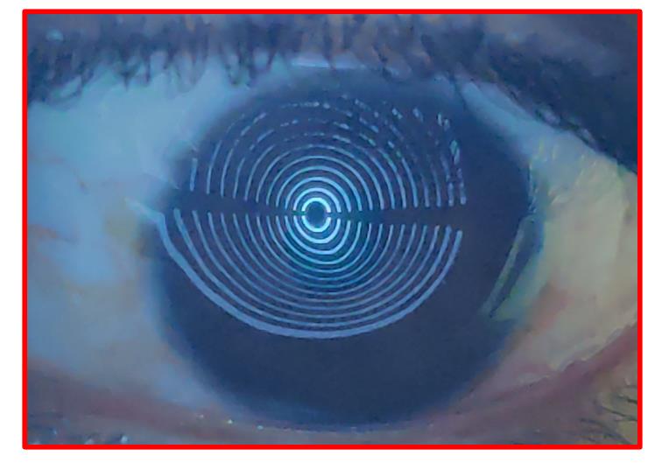
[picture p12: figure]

5. Mires bleeding out of iris region into the sclera.

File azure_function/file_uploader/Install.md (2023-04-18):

# Steps to set up backend
-------------------------------
Below instruction is to setup backend to automatically upload the generated files in the android app to the Blob store.
## Setting up the azure function
1. Search for Function App in the market place
2. Click on create a function app, in the form that appears:
  0. Modify the prefilled fields if required. 
  1. Fill in the azure function app name. Example: smartKcFunctions
  2. Choose runtime to be `Python`
  3. Choose operating system as `Linux`
3. Click on `Next > Hosting`
4. Select a storage account or else create a new storage account if there is no existing storage account
5. Click on `Review + Create` from top
## Setup local environment for Azure function
Once, you have created a function app, you need to create a local environment to publish a new function under the created function app.
### Prerequisites
1. [The Azure Functions Core Tools](https://learn.microsoft.com/en-us/azure/azure-functions/functions-run-local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) version 4.x.
2. Python versions that are supported by Azure Functions. For more information, see How to install [Python](https://wiki.python.org/moin/BeginnersGuide/Download).
3. [Visual Studio Code](https://code.visualstudio.com/)
4. The [Python extension](https://marketplace.visualstudio.com/items?itemName=ms-python.python) for Visual Studio Code.
5. The [Azure Functions extension](https://marketplace.visualstudio.com/items?itemName=ms-azuretools.vscode-azurefunctions) for Visual Studio Code, version 1.8.3 or a later version.

### Create a local project
1. Open a new empty folder with Visual Studio Code
2. Choose the Azure icon in the Activity bar. Then in the `Workspace (local) area`, select the `+` button
3. Choose `Create HTTP function`
4. Select `Python` when prompted for select a language.
5. Select `Skip virtual environment` when prompted for selecting interpreter path.
6. Name your Http function. For eg. `fileUploader`.
7. From the github repository, Under the folder `azure_function/uploader/smart_kc_test_uploader` copy files `function.json` and `host.json` and paste it to your respective `function.json` and `host.json`
8. Copy the above step with `azure_function/uploader/requirements.txt` and paste it to your respective `requirements.txt`
9. Make sure the app runs by typing: `func start` in the terminal open inside `azure_function/uploader`
### Publish the function
1. Publish the function by running the command `func azure functionapp publish [YourFunctionAppName]`

### Set Environment for the function
Certain variables need to be setup for the azure function. Follow these steps to set this up:
1. Go to the Azure Function resource
2. Click on the `Configuration` under `Settings` section
3. Under `Application settings` tab click on `New application setting`
4. On the new dialogue box that appears, enter name of the variable as `upload_secret` and put in a strong secret. 
5. Click `OK` to save the variable.
6. Click `Save` at the top to save the application settings.
7. Click `Continue` on the warning if it appears.

### Give Blob permissions to Azure function
To upload files in the blob storage azure function needs certain permissions. Follow below steps to set it up.
1. Go to your Azure function App.
2. Click on `Identity` under `Settings`
3. Under the `System Assigned` tab, turn the `Status` switch to On and click `Save` on the top.
4. After you click `Save`, Click the button that will appear as `Add Azure Role Assignments`.
5. On the new page that appears, Click `Add role Assignments`.
6. Next, select scope as `Storage`. Then, select a storage resource where you want the files to be uploaded. Further, select the role as `Blob Storage Contributor role`
7. Click `Save`

### Get URL for Azure function
To get the URL of Azure function, go to the function app in your azure portal. Under `Funcions` click the Azure function created by you and click on `Get Function Url` present on the top.
### Use the credentials in the app
1. Open the android app and click on `UPDATE PREFS`.
2. Turn on the switch labelled as `Upload Enabled`
3. Enter Azure function URL on the `Upload URL` field.
4. Enter Uplaod Secret on the `Upload Secret` field.
5. Click `Save`
Now, the app can be used to upload images, simply click on `Upload Files` in the homescreen after clicking the images.

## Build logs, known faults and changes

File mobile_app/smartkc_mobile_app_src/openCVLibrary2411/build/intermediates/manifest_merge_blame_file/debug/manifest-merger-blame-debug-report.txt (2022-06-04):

1<?xml version="1.0" encoding="utf-8"?>
2<manifest xmlns:android="http://schemas.android.com/apk/res/android"
3    package="org.opencv"
4    android:versionCode="24110"
5    android:versionName="2.4.11" >
6
7    <uses-sdk
8        android:minSdkVersion="21"
8-->C:\Users\t-sigai\AndroidStudioProjects\KT_14_opencv\openCVLibrary2411\src\main\AndroidManifest.xml
9        android:targetSdkVersion="29" />
9-->C:\Users\t-sigai\AndroidStudioProjects\KT_14_opencv\openCVLibrary2411\src\main\AndroidManifest.xml
10
11</manifest>

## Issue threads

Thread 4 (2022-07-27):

Uncertain results, and rink_distribution settings

jaggzh, 2022-07-27:
I redesigned the 3d model to be printed with FDM instead of SLA.
My resulting processing is pretty messed up, and I'm wondering if the ring_distribution needs to be set specific to the cone's variation, but I don't know how to go about calibrating and creating a ring_distribution file.
Here's an mp_clean of mine:

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

My col.png:
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

An axlal_map_overlay:
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

And an original jpg:
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

jaggzh, 2022-07-30:
I prepared a comparison of working distances for the print I did.  Is it possible to determine which is the proper one?
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

mohja1, 2022-10-25:
Sorry for the late response. We updated the phone attachment folder and added more details about the print and assembly here: https://github.com/microsoft/SmartKC-A-Smartphone-based-Corneal-Topographer/tree/main/hardware
Hope that helps.

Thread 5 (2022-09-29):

How to evaluate gap_top with python scripts

jaggzh, 2022-09-29:
I'm trying to find, in the python code, how we can go about obtaining and setting the gap_base, as it differs between mobile devices (the distance between camera and base of placido attachment).  (Section 5.3 of pdf, down at "Measuring camera-attachment distance").

Anyone know?  I can't find support for it.

sidgairo18, 2022-10-10:
Hi,

parser.add_argument(
    "--gap2",
    default=5,
    type=float,
    help="Accounting for gap (in mm) between camera pupil and smallest ring.",
)

setting `args.gap2` should do the job.
args.gap2 -> gap_base
args.gap1 -> gap_top

args.gap2 should be identified for a phone and placido setup, and fixed then.

```
# call function to run pipeline and generate_topography_maps
# expects image to be in .jpg format
error = corneal_top_obj.generate_topography_maps(
    base_dir,
    image_name,
    center=center,
    downsample=True,
    blur=True,
    err1=[args.gap1],
    err2=[args.gap2],
    )
```

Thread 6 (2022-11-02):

Customised Zernike?

jasonmnemonic, 2022-11-02:
Hi. Thank you for the interesting work.

Just wondering where if your `zernike.py` which you have modified on the make_cart_grid? See below. Thanks.

> External Libraries
[Zernike](https://github.com/jacopoantonello/zernike)
[Fingerprint-Enhancement-Python](https://github.com/Utkarsh-Deshmukh/Fingerprint-Enhancement-Python)
Note: The zernike polynomial smoothening function has been modified from the version above. Please use the module at location: /SmartKC/data/zernike (I yet am to make a pull request to the original repository).

jasonmnemonic, 2022-11-02:
Actually, I found it in another thread.

https://github.com/microsoft/SmartKC-A-Smartphone-based-Corneal-Topographer/issues/1

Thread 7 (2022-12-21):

Arc-step model_file / ring_distribution maths

jasonmnemonic, 2022-12-21:
Hi,

In the method `get_arc_step_params`, it refers to the `model_file` or the `ring_distribution` file and does the maths for the **ring radius** (column 0) and **its working distance from the cone's first ring** at the base (column 1).

Some excerpt from the file:
```
4.0 0.0
5.7 10.9
7.0 19.3
8.1 25.9
8.9 31.2
9.6 35.6
10.2 39.4
10.7 42.6
...
```

How does the maths in:
```
model.append(
                (
                    # uncomment and use below in-case of oldest placido head
                    (model_temp[idx][0] + model_temp[idx + 1][0] - 2 + 0.5) / 2.0,
                    #(model_temp[idx][0] + model_temp[idx + 1][0]) / 2.0,
                    (model_temp[idx][1] + model_temp[idx + 1][1]) / 2.0,
                )
            )
```
What is the numbers for `-2 + 0.5` mean (what they refer to)?

Thanks.

mohja1, 2022-12-30:
Good question.

We did this to adjust for the thickness of each ring (-2 was added as the inner diameter was 2 mm smaller than the outer diameter, with the ring thickness being 1mm). Due to this thickness, we need to adjust for the available space allowing the light to pass out. To compute the adjustment factor, we minimized that parameter for the reconstruction on a set of test images and found it to be 0.5 mm.

mohja1, 2022-12-30:
Good question.
We did this to adjust for the thickness of each ring (-2 was added as the inner diameter was 2 mm smaller than the outer diameter, with the ring thickness being 1mm). Due to this thickness, we need to adjust for the available space allowing the light to pass out. To compute the adjustment factor, we minimized that parameter for the reconstruction on a set of test images and found it to be 0.5 mm.

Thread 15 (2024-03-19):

Design issues

Sajadkim, 2024-03-19:
Is it possible to modify the internal design of the Placido base by increasing the thickness of the columns of the internal cone and increasing its thickness a little, because there is no MJF printing in my country, only resin and flint without affecting the code and the program?

mohja1, 2024-03-20:
You can definitely give it a shot.
One of the problems that we faced with resin prints was that it was tricky to remove the "supports". It resulted in bad edges obstructing light or breakage of a few mires.

sidgairo18, 2024-03-20:
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

Yes, I agree with Mohit, you can give it a shot. Another factor to be careful about is, when you increase the width/thickness of the columns in the internal cone, this will lead to wider gaps in the mire image as well (see horizontal empty spaces in attached image), which then might lead to inaccurate reconstructions.

Have fun building SmartKC :)

Sajadkim, 2024-03-21:
Thank you very much sir for the reply. I encountered problems when printing the Placido base using resin or filament. The inner cone breaks, so I will order it to be printed from outside the country. My question is whether the design, if printed using MJF, will withstand and be strong. This is the characteristics of the piece and the material is PA12 nylon.
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

sidgairo18, 2024-03-22:
MJF printed Placido is reasonably strong.

about the material @mohja1 would be able to confirm.

Thanks!

mohja1, 2024-03-22:
Yes, it is strong. We used MJF PA12 in Natural Grey color with Matte finish.

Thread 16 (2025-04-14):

Missing STL file for Placido attachment part

ZeroCool2017, 2025-04-14:
Hi there, thanks for sharing this awesome project!

I was going through the hardware folder and found the STL files for the placido base, diffuser, and head, but I didn’t see the STL for the attachment part that connects the system (e.g., to the phone or mount). Could you let me know where to find it, or if it can be added to the repo?

Thanks so much!

Closed 2025-04-14.

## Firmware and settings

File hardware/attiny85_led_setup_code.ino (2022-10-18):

// SmartKC dev board code
#include <Adafruit_NeoPixel.h>

// Pin on the ATtiny85 board connected to the LED
#define PIN            1

// Number of LED's connected to the ATtiny85 board
#define NUMPIXELS      12

// To setup the LED ring library (NeoPixel), we pass number of LED's and pin number to send signals to as parameters.
// Note: For older NeoPixel LED rings, we might need to change the third parameter.
Adafruit_NeoPixel pixels = Adafruit_NeoPixel(NUMPIXELS, PIN, NEO_RGB + NEO_KHZ800);

// Delay for half a second
int delayval = 500; 

void setup() {
  // Initializes the NeoPixel library
  pixels.begin(); 
}

void loop() {
  // For a set of NeoPixel LEDs, the first NeoPixel is 0, second is 1, all the way up to the count of pixels minus one.
  for(int i=0; i<NUMPIXELS; i++){
    // pixels.Color takes RGB values, from 0,0,0 up to 255,255,255 in the GRB order
    pixels.setPixelColor(i, pixels.Color(255,200,255));
    // Send the updated pixel color to the hardware.
    pixels.show();
    // Delay for a period of time (in milliseconds).
    delay(delayval); 
  }
}

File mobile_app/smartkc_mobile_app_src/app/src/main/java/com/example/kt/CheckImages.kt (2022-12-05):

package com.example.kt

import android.content.Intent
import android.graphics.Bitmap
import android.graphics.BitmapFactory
import android.graphics.Matrix
import android.media.ExifInterface
import android.net.Uri
import android.os.AsyncTask
import android.os.Bundle
import android.util.Log
import android.view.View
import android.widget.Button
import android.widget.TextView
import androidx.appcompat.app.AppCompatActivity
import com.example.kt.data.repo.FileRepository
import org.apache.commons.io.comparator.LastModifiedFileComparator
import com.github.chrisbanes.photoview.PhotoView
import com.opencsv.CSVWriter
import dagger.hilt.android.AndroidEntryPoint
import kotlinx.coroutines.runBlocking
import org.opencv.imgproc.Imgproc
import org.opencv.android.Utils
import org.opencv.core.*
import java.io.File
import java.io.FileNotFoundException
import java.io.FileWriter
import java.io.IOException
import java.lang.Exception
import java.text.SimpleDateFormat
import java.util.*
import javax.inject.Inject

@AndroidEntryPoint
class CheckImages : AppCompatActivity(), View.OnClickListener {

    // File Repository
    @Inject
    lateinit var fileRepository: FileRepository

    val image_checker = ImageCheck()

    /** Called when the activity is first created.  */
    private var image_index = 0
    private var maxCounts = 0
    private var origMaxCounts = 0
    private lateinit var imageFiles: Array<File>

    // offset distance measure
    var offset_distance = -1.0

    //public class variables
    var dir_name: String? = null
    var left_right: String? = null
    var hash_map: HashMap<String, String>? = null
    var centerCutoff = 1.0f
    public override fun onCreate(savedInstanceState: Bundle?) {
        super.onCreate(savedInstanceState)
        setContentView(R.layout.activity_checkimages)

        // retrieve getExtras
        val bundle = intent.extras
        dir_name = bundle!!.getString("dir_name")
        left_right = bundle.getString("left_right")
        hash_map = intent.getSerializableExtra("hash_map") as HashMap<String, String>?
        origMaxCounts = bundle.getString("number_of_images")!!.toInt()
        image_index = 0 // initialize image index as 0

        // get app preferences
        val sharedPrefs = getSharedPreferences("KT_APP_PREFERENCES", MODE_PRIVATE)
        centerCutoff = sharedPrefs.getFloat("CENTER_CUTOFF", 0.5f)

        // list images in the directory
        val dir = File(
            getExternalFilesDir(null),
            MainActivity.PACKAGE_NAME + "/" + dir_name
        )
        imageFiles = dir.listFiles { dir, name ->
            name.lowercase(Locale.getDefault()).startsWith(
                left_right!!
            )
        }
        Arrays.sort(imageFiles, LastModifiedFileComparator.LASTMODIFIED_REVERSE)
        // incase there are less number of images than maxCounts
        maxCounts = Math.min(imageFiles.size, origMaxCounts)
        //Log.e("Counts", "maxCounts "+maxCounts);

        // previous
        val btnNo = findViewById<View>(R.id.no_btn) as Button
        btnNo.setOnClickListener(this)

        // next
        val btnYes = findViewById<View>(R.id.yes_btn) as Button
        btnYes.setOnClickListener(this)

        // remove view
        removeView()
        // show image
        //showImage();
        AsyncTask.execute { showImage() }
    }

    private fun showImage() {

        //PhotoView imgView = (PhotoView) findViewById(R.id.myimage);
        //imgView.setImageURI(Uri.fromFile(imageFiles[image_index]));

        // check if file is empty
        val fileEmpty = imageFiles[image_index].exists() && imageFiles[image_index].length() == 0L
        if (fileEmpty) {
            // emulate click
            runOnUiThread { pressNo() }
            return
        } else {
            // Find and display center, check if No then disable Yes
            var check = false
            check = try {
                checkCenter(imageFiles[image_index].toString(), centerCutoff)
            } catch (e: Exception) {
                runOnUiThread { pressNo() }
                e.printStackTrace()
                Log.e("CHECK_IMAGES", "Center not found or empty image!")
                return
            }
            if (!check) {
                runOnUiThread {
                    val btnYes = findViewById<View>(R.id.yes_btn) as Button
                    btnYes.isClickable = false
                    btnYes.visibility = View.GONE
                    val questionView = findViewById<TextView>(R.id.questionView)
                    questionView.text = "The image is not good!"
                }
            }
            runOnUiThread { // set prompt text and Image view
                val textView = findViewById<View>(R.id.textView) as TextView
                if (left_right == "right") textView.text =
                    "Right Eye: Image " + (image_index + 1) + "/" + maxCounts else textView.text =
                    "Left Eye: Image " + (image_index + 1) + "/" + maxCounts
            }
            return
        }
    }
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

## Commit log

2021-11-22 Adding analysis pipeline for open-sourcing
    [kt_calib_gap2_config1.txt, kt_calib_gap2_config2.txt]
2021-11-22 clean output
    [kt_calib_gap2_config1.txt, kt_calib_gap2_config2.txt]
2022-01-18 Adding Placido head .stl file
    [placido_head.stl]
2022-06-04 updating mobile app and placido stl files
    [base_clip.stl, placido_head.stl]
2022-06-04 update readme with details on app and attachment
2022-10-18 Added hardware folder with stl files, arduino code, and instructions.
    [base_clip.stl, diffuser.stl, placido_base.stl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]
2023-01-19 Fix: Do not run checks on URL input when upload is disabled
    [UpdatePreferences.kt]
2023-02-07 Add: Allow user to select camera
2023-02-24 Uploading step files of placido design
    [diffuser.step, placido_base.step, placido_head.step]
2023-03-14 Update: zoom factor to 1 in camera activity
2023-03-14 Update: Show error msg after analysing image and show yes button for every analysed image
2023-03-14 Update: Switch instead of buttons for toggling locks in camera view
2023-03-14 Fix: Show Image for no center detection stage in check images view
2023-03-22 Fix: Remove crash library that paused UI thread on a crash
2023-03-23 Fix: App crash when patient age and id are empty
    [DataActivity.java]
2023-04-12 Updating sample images and their heatmap results
2023-04-24 Add: Pickup camera specs from app
2023-06-11 refactor: change column names to snake case in csv
2023-06-22 add commandline argument --output_dir for specifying the output directory. Default stays to be the current date.
2023-07-04 chore: remove print
2023-10-20 feat: (1) add nans as constants (2) add median filtering with nans
2024-02-26 feat: add heatmap masking for missing points
2024-02-26 fix: csv file parsing issues + refactor: invert 3d corneal shape + feat: add heatmap masking for missing points
2026-08-24 Pin GitHub Actions to full-length commit SHAs
